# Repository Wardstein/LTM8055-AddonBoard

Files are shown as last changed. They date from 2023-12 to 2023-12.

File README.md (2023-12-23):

# LTM8055 Addon Board



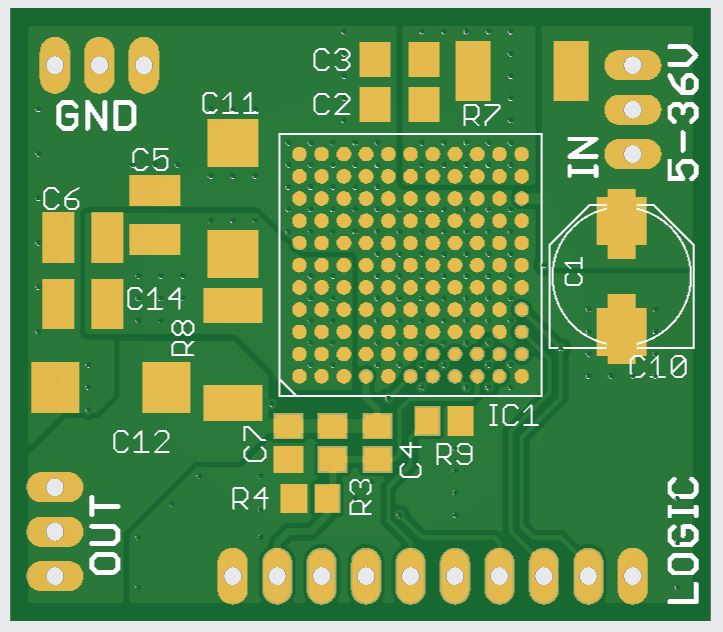
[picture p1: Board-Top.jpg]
Board Top Side


This is a small 4 layer addon board with an [LTM8055(-1) DCDC regulator](https://www.analog.com/en/products/ltm8055.html), featuring an INA138 for output current measurement (as the internal current monitor output of the LTM8055 is not very accurate). Additionally a lot of the LTM8055 configuration pins are broken out to a header to be used on the base-board. But this small addon board can also be used as a standalone board, just fit the voltage feedback resistors on this board.

The LTM8055 is a 5-36V input, 8,5A Buck-Boost μModule Regulator with step-up and -down capability from 1,2V to 36V output.

Why use an addon board? This was developed, as the LTM8055 µModules are BGA parts, which are not the easiest parts for home use and soldering. This module can be very easily be soldered on a hotplate (I use the Miniware MHP30).

This board is for example used in the [joseng.de Lab-Box project](https://github.com/Wardstein/Lab-Box) in the multi-power-supply module. 

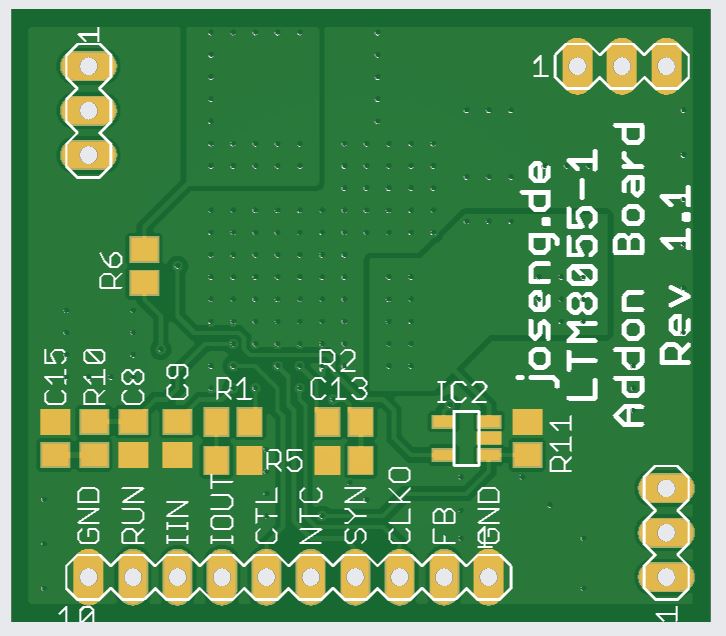
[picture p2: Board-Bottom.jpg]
Board Bottom Side


# License
The content of this whole repository is licensed under [CERN-OHL-W v2](License/cern_ohl_w_v2.txt) or later by Jonas Eberhard.

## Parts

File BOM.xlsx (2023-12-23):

Count | Designator | Part | Order Number Mouser | Comment
2 | C2, C3 | CL31B475KBHNNNF - 4,7µ 50V 1206 X7R | 187-CL31B475KBHNNNF
2 | C2, C3 | UMK316AB7475KL-T - 4,7µ 50V 1206 X7R | 963-UMK316AB7475KL-T | ALTERNATIVE
1 | C10 | T495D226K035ATE300 - Tantal 35V 22uF 2917 | 80-T495D226K35ATE300
1 | C12 | TPSD226K025R0300 - Tantal 22µ 25V 300mOhm | 581-TPSD226K025R0300 | Might need to be adapted depending on the desired output voltage of the regulator
3 | C5, C6, C14 | CL32B226KAJNNNE - 22µ 25V 1210 X7R | 187-CL32B226KAJNNNE | Might need to be adapted depending on the desired output voltage of the regulator
1 | C8 | 47pF 50V
1 | C15 | 3,3nF 50V
1 | C7 | 10nF 50V
1 | C9 | 220nF 50V
1 | IC1 | LTM8055EY | 584-LTM8055EY#PBF
1 | IC1 | LTM8055EY-1 | 584-LTM8055EY-1#PBF | ALTERNATIVE
1 | IC2 | INA138NA/3K | 595-INA138NA/3K
2 | R7, R8 | Shunt 5mOhm 2512 | 708-CSNL2512FT5L00
1 | R2 | 0 Ohm 0805
1 | R5 | 3,3k 0805
1 | R10 | 6,81k 0805
3 | R1, R6, R11 | 33k 0805
1 | R9 | NTC 10k - NTCS0805E3103FMT | 594-NTCS0805E3103FMT
1 | SV1, SV2, SV3, SV4 | Pin headers cut from one big part | 571-2-825433-0

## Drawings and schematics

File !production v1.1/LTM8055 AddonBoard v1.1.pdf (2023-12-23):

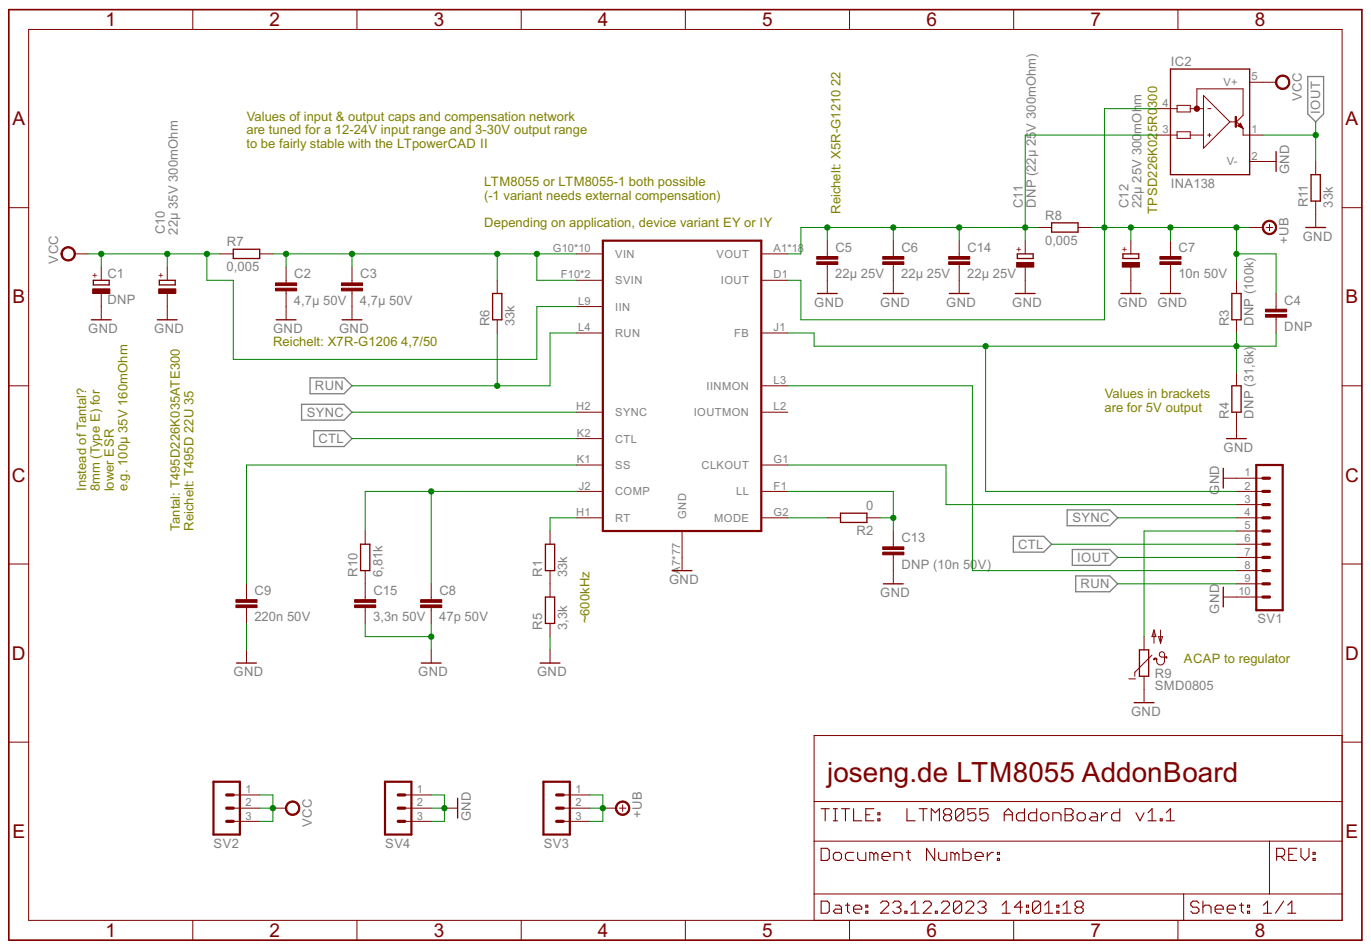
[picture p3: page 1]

Tantal: T495D226K035ATE300 Reichelt: T495D 22U 35 Values of input & output caps and compensation network are tuned for a 12-24V input range and 3-30V output range

LTM8055 or LTM8055-1 both possible
(-1 variant needs external compensation)

Depending on application, device variant EY or IY

Values in brackets are for 5V output

10

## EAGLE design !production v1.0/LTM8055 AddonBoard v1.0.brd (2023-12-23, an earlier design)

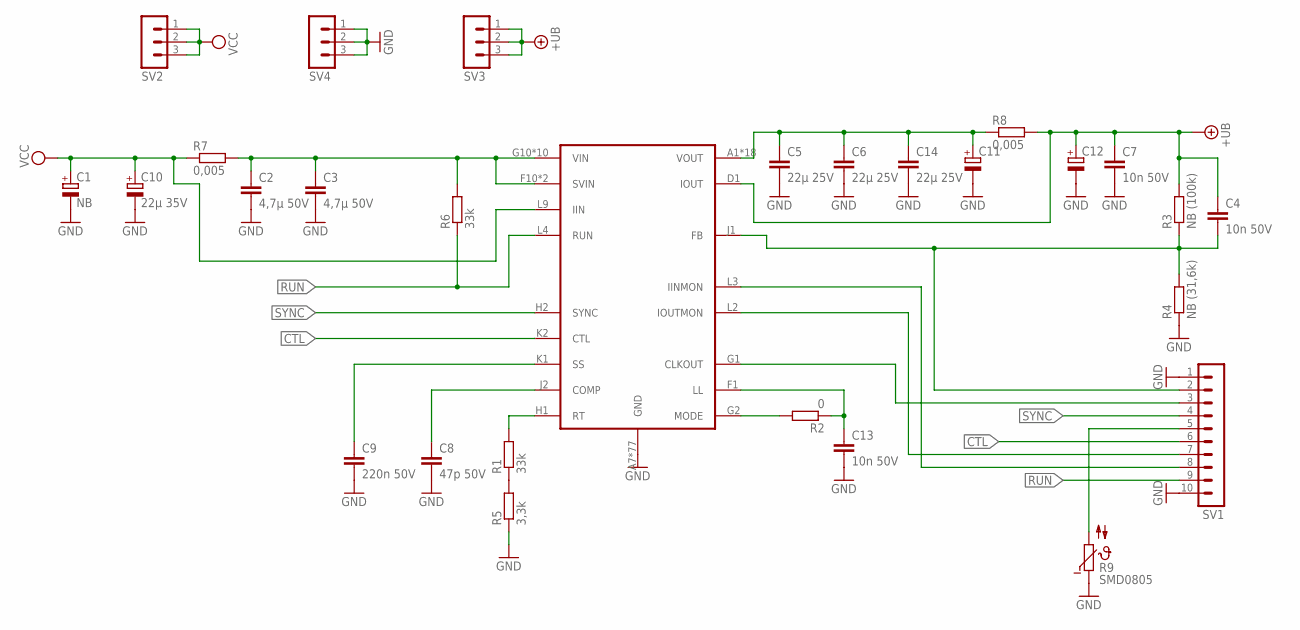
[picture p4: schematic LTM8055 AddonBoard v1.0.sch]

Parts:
C1: NB; PANASONIC_E
C2, C3: 4,7µ 50V; C1206
C4, C7, C13: 10n 50V; C0805
C5, C6, C14: 22µ 25V; C1210
C8: 47p 50V; C0805
C9: 220n 50V; C0805
C10: 22µ 35V; D/7343-31R
C11, C12: CPOL-EUD/7343-31R; D/7343-31R
IC1: LTM8055-1; BGA121_1.27_15X15MM
R1, R6: 33k; R0805
R2: 0; R0805
R3: NB (100k); R0805
R4: NB (31,6k); R0805
R5: 3,3k; R0805
R7, R8: 0,005; R2512
R9: SMD0805; R0805
SV1: MA10-1
SV2, SV3, SV4: MA03-1

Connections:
+UB: C4.1, C7.1, C12.+, IC1.D1 (IOUT), R3.2, R8.2, SV3.1, SV3.2, SV3.3
CTL: IC1.K2 (CTL), SV1.6
GND: C1.-, C2.2, C3.2, C5.2, C6.2, C7.2, C8.2, C9.2, C10.-, C11.-, C12.-, C13.2, C14.2, IC1.A7 (GND), IC1.A8 (GND), IC1.A9 (GND), IC1.A10 (GND), IC1.A11 (GND), IC1.B7 (GND), IC1.B8 (GND), IC1.B9 (GND), IC1.B10 (GND), IC1.B11 (GND), IC1.C7 (GND), IC1.C8 (GND), IC1.C9 (GND), IC1.C10 (GND), IC1.C11 (GND), IC1.D2 (GND), IC1.D3 (GND), IC1.D4 (GND), IC1.D5 (GND), IC1.D6 (GND), IC1.D7 (GND), IC1.D8 (GND), IC1.D9 (GND), IC1.D10 (GND), IC1.D11 (GND), IC1.E1 (GND), IC1.E2 (GND), IC1.E3 (GND), IC1.E4 (GND), IC1.E5 (GND), IC1.E6 (GND), IC1.E7 (GND), IC1.E8 (GND), IC1.E9 (GND), IC1.E10 (GND), IC1.E11 (GND), IC1.F2 (GND), IC1.F3 (GND), IC1.F4 (GND), IC1.F5 (GND), IC1.F6 (GND), IC1.F7 (GND), IC1.F8 (GND), IC1.F9 (GND), IC1.G3 (GND), IC1.G4 (GND), IC1.G5 (GND), IC1.G6 (GND), IC1.G7 (GND), IC1.G8 (GND), IC1.G9 (GND), IC1.H3 (GND), IC1.H4 (GND), IC1.H5 (GND), IC1.H6 (GND), IC1.H7 (GND), IC1.H8 (GND), IC1.H9 (GND), IC1.J3 (GND), IC1.J4 (GND), IC1.J5 (GND), IC1.J6 (GND), IC1.J7 (GND), IC1.J8 (GND), IC1.J9 (GND), IC1.K3 (GND), IC1.K4 (GND), IC1.K5 (GND), IC1.K6 (GND), IC1.K7 (GND), IC1.K8 (GND), IC1.K9 (GND), IC1.L1 (GND), IC1.L5 (GND), IC1.L6 (GND), IC1.L7 (GND), IC1.L8 (GND), R4.1, R5.1, R9.1, SV1.1, SV1.10, SV4.1, SV4.2, SV4.3
unnamed: C13.1, IC1.F1 (LL), R2.1
unnamed: IC1.G2 (MODE), R2.2
unnamed: IC1.G1 (CLKOUT), SV1.3
unnamed: C9.1, IC1.K1 (SS)
unnamed: C4.2, IC1.J1 (FB), R3.1, R4.2, SV1.2
unnamed: IC1.L2 (IOUTMON), SV1.7
unnamed: IC1.L3 (IINMON), SV1.8
unnamed: IC1.H1 (RT), R1.2
unnamed: C2.1, C3.1, IC1.F10 (SVIN), IC1.F11 (SVIN), IC1.G10 (VIN), IC1.G11 (VIN), IC1.H10 (VIN), IC1.H11 (VIN), IC1.J10 (VIN), IC1.J11 (VIN), IC1.K10 (VIN), IC1.K11 (VIN), IC1.L10 (VIN), IC1.L11 (VIN), R6.2, R7.2
unnamed: R1.1, R5.2
unnamed: C8.1, IC1.J2 (COMP)
unnamed: R9.2, SV1.5
unnamed: C5.1, C6.1, C11.+, C14.1, IC1.A1 (VOUT), IC1.A2 (VOUT), IC1.A3 (VOUT), IC1.A4 (VOUT), IC1.A5 (VOUT), IC1.A6 (VOUT), IC1.B1 (VOUT), IC1.B2 (VOUT), IC1.B3 (VOUT), IC1.B4 (VOUT), IC1.B5 (VOUT), IC1.B6 (VOUT), IC1.C1 (VOUT), IC1.C2 (VOUT), IC1.C3 (VOUT), IC1.C4 (VOUT), IC1.C5 (VOUT), IC1.C6 (VOUT), R8.1
RUN: IC1.L4 (RUN), R6.1, SV1.9
SYNC: IC1.H2 (SYNC), SV1.4
VCC: C1.+, C10.+, IC1.L9 (IIN), R7.1, SV2.1, SV2.2, SV2.3

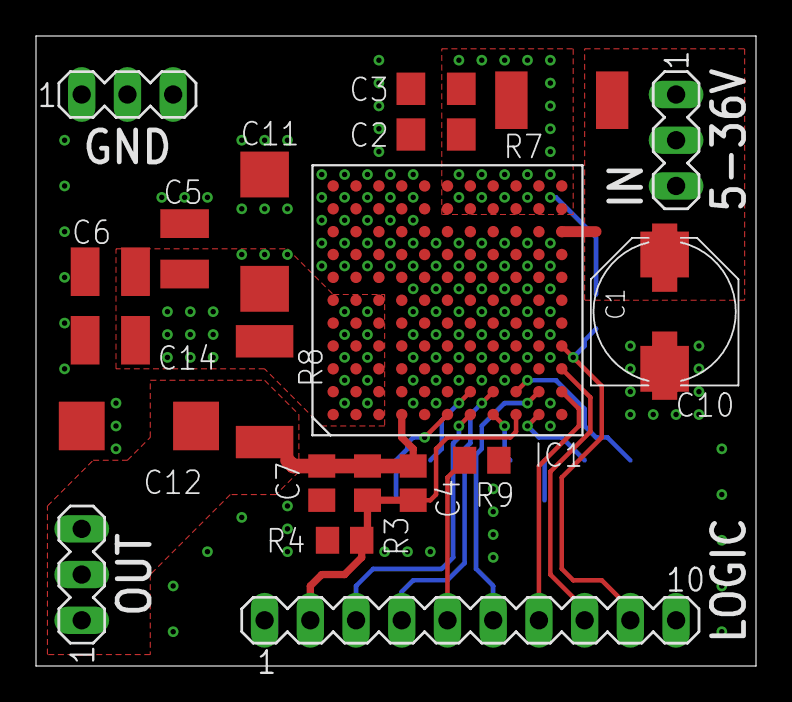
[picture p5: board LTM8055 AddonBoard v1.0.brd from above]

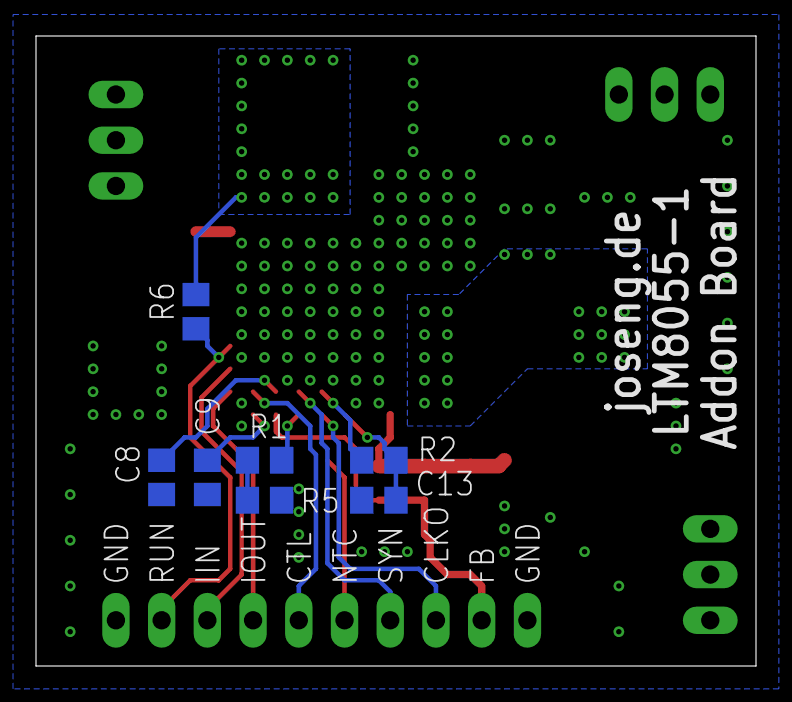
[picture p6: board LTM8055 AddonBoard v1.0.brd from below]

Board: 4 copper layers, 40.0 x 35.0 mm, 28 parts (7 on the bottom side), 19 nets.
